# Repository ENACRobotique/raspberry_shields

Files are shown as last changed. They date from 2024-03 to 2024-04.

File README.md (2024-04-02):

# raspberry_shields
Custom shields for raspberrypi

Documentations : 

- [Page wweb raspberrypi](https://www.raspberrypi.com/documentation/computers/raspberry-pi.html)
- [Datasheet BCM2711 ](https://datasheets.raspberrypi.com/bcm2711/bcm2711-peripherals.pdf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..)
 
Les broches des VL53 1 et 2  sont sur des broches pwm

Les uart suivent la norme  Rx, Tx, 3v3, 5v, GND (pdv raspi)

Attention a la configuration PULL UP ou DOWN des gpios ( voir datasheet )

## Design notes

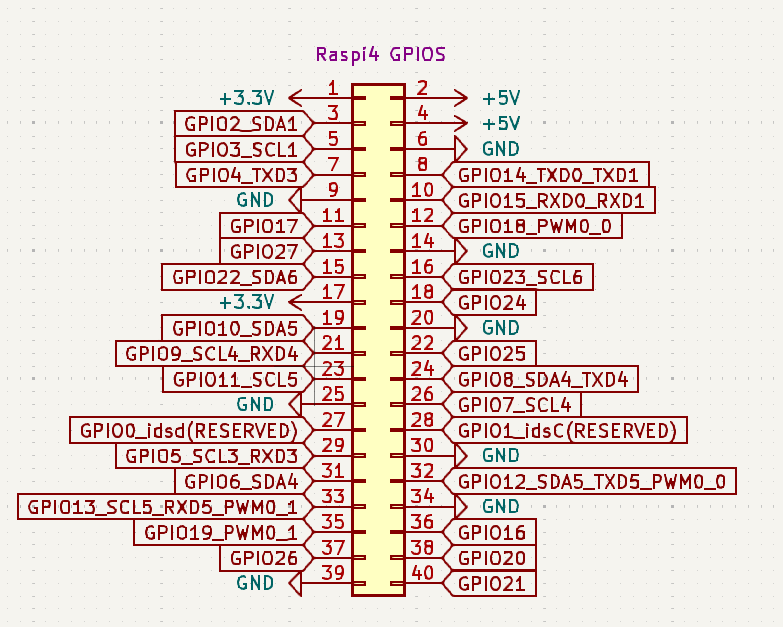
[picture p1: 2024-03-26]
rpi4b/rpi4_gpio.png

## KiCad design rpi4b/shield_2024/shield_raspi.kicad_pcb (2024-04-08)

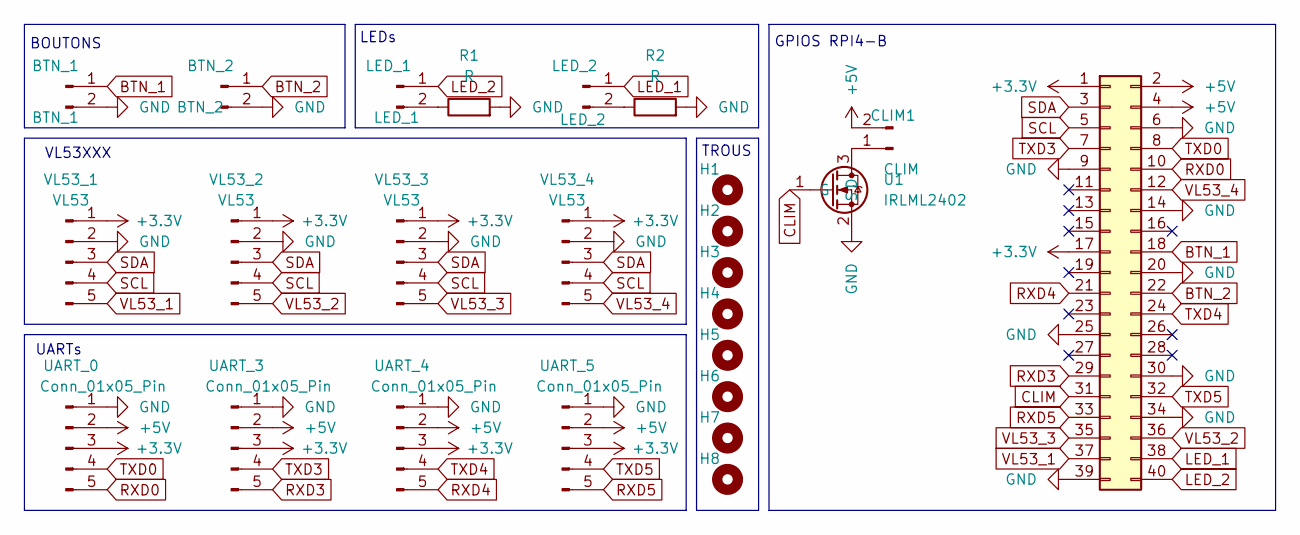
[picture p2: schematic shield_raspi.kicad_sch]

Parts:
BTN_1: BTN_1; PinHeader_1x02_P2.54mm_Vertical
BTN_2: BTN_2; PinHeader_1x02_P2.54mm_Vertical
CLIM1: CLIM; PinHeader_1x02_P2.54mm_Vertical
H1, H2, H3, H4, H5, H6, H7, H8: MountingHole; MountingHole_3.2mm_M3
J4: Conn_02x20_Odd_Even; PinSocket_2x20_P2.54mm_Vertical
LED_1: LED_1; PinHeader_1x02_P2.54mm_Vertical
LED_2: LED_2; PinHeader_1x02_P2.54mm_Vertical
R1, R2: R; R_0603_1608Metric
U1: IRLML2402; SOT-23
UART_0, UART_3, UART_4, UART_5: Conn_01x05_Pin; Molex_CLIK-Mate_502382-0570_1x05-1MP_P1.25mm_Vertical
VL53_1, VL53_2, VL53_3, VL53_4: VL53; PinHeader_1x05_P2.54mm_Vertical

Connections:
+3.3V: J4.1, J4.17, UART_0.3, UART_3.3, UART_4.3, UART_5.3, VL53_1.1, VL53_2.1, VL53_3.1, VL53_4.1
+5V: CLIM1.2, J4.2, J4.4, UART_0.2, UART_3.2, UART_4.2, UART_5.2
BTN_1: BTN_1.1, J4.18
BTN_2: BTN_2.1, J4.22
CLIM: J4.31, U1.1 (G)
GND: BTN_1.2, BTN_2.2, J4.6, J4.9, J4.14, J4.20, J4.25, J4.30, J4.34, J4.39, R1.2, R2.2, U1.2 (S), UART_0.1, UART_3.1, UART_4.1, UART_5.1, VL53_1.2, VL53_2.2, VL53_3.2, VL53_4.2
LED_1: J4.38, LED_2.1
LED_2: J4.40, LED_1.1
unnamed: CLIM1.1, U1.3 (D)
unnamed: LED_1.2, R1.1
unnamed: LED_2.2, R2.1
RXD0: J4.10, UART_0.5
RXD3: J4.29, UART_3.5
RXD4: J4.21, UART_4.5
RXD5: J4.33, UART_5.5
SCL: J4.5, VL53_1.4, VL53_2.4, VL53_3.4, VL53_4.4
SDA: J4.3, VL53_1.3, VL53_2.3, VL53_3.3, VL53_4.3
TXD0: J4.8, UART_0.4
TXD3: J4.7, UART_3.4
TXD4: J4.24, UART_4.4
TXD5: J4.32, UART_5.4
VL53_1: J4.37, VL53_1.5
VL53_2: J4.36, VL53_2.5
VL53_3: J4.35, VL53_3.5
VL53_4: J4.12, VL53_4.5

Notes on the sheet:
VL53XXX
UARTs
LEDs
TROUS
BOUTONS
GPIOS RPI4-B

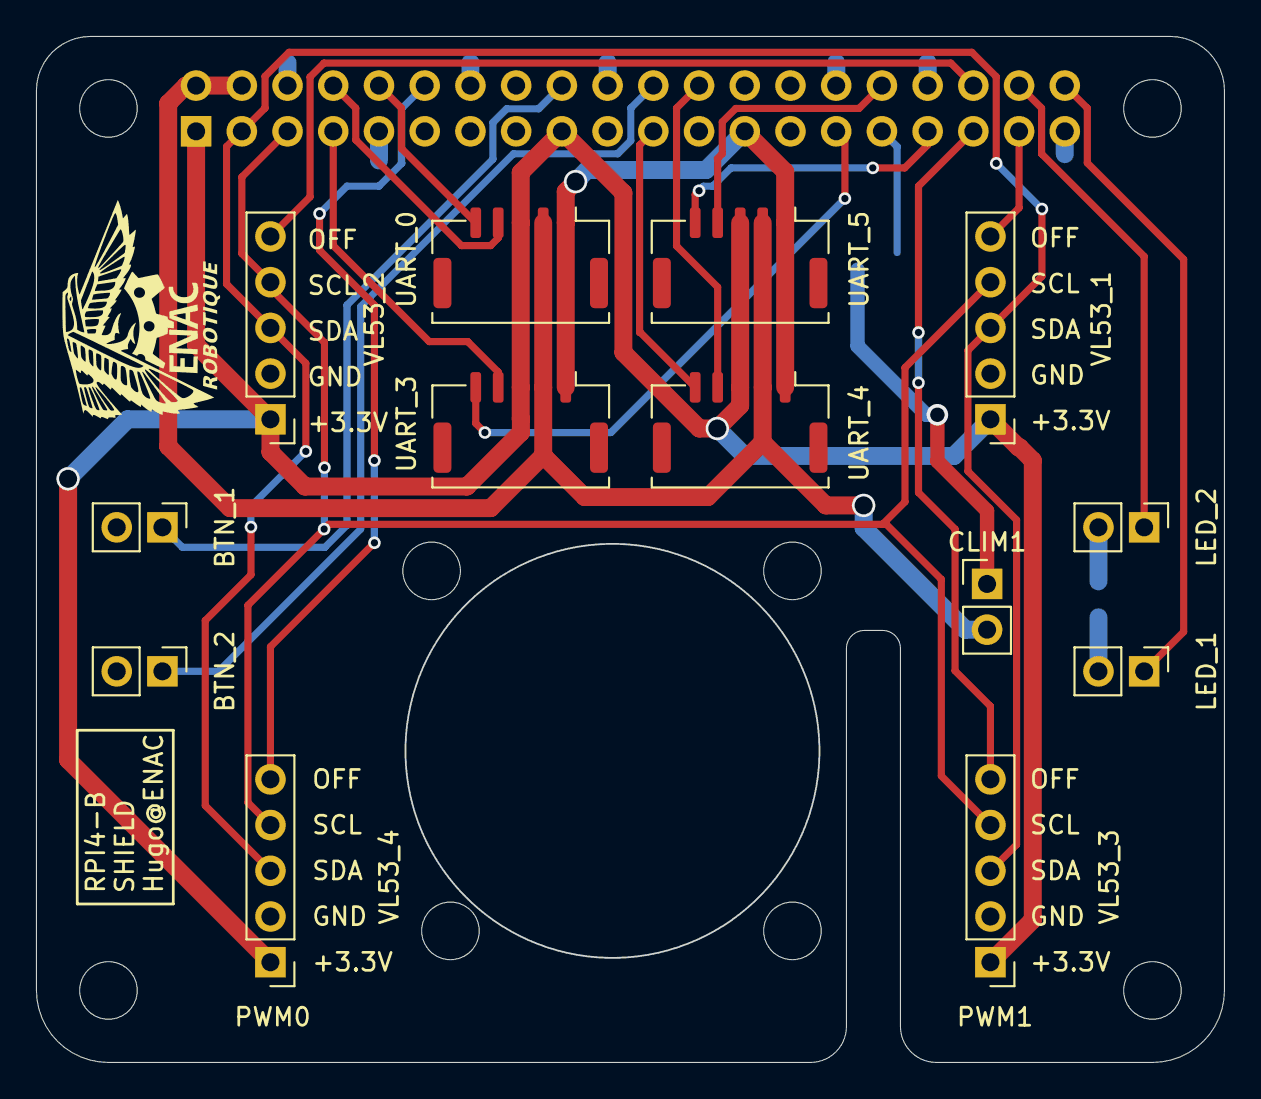
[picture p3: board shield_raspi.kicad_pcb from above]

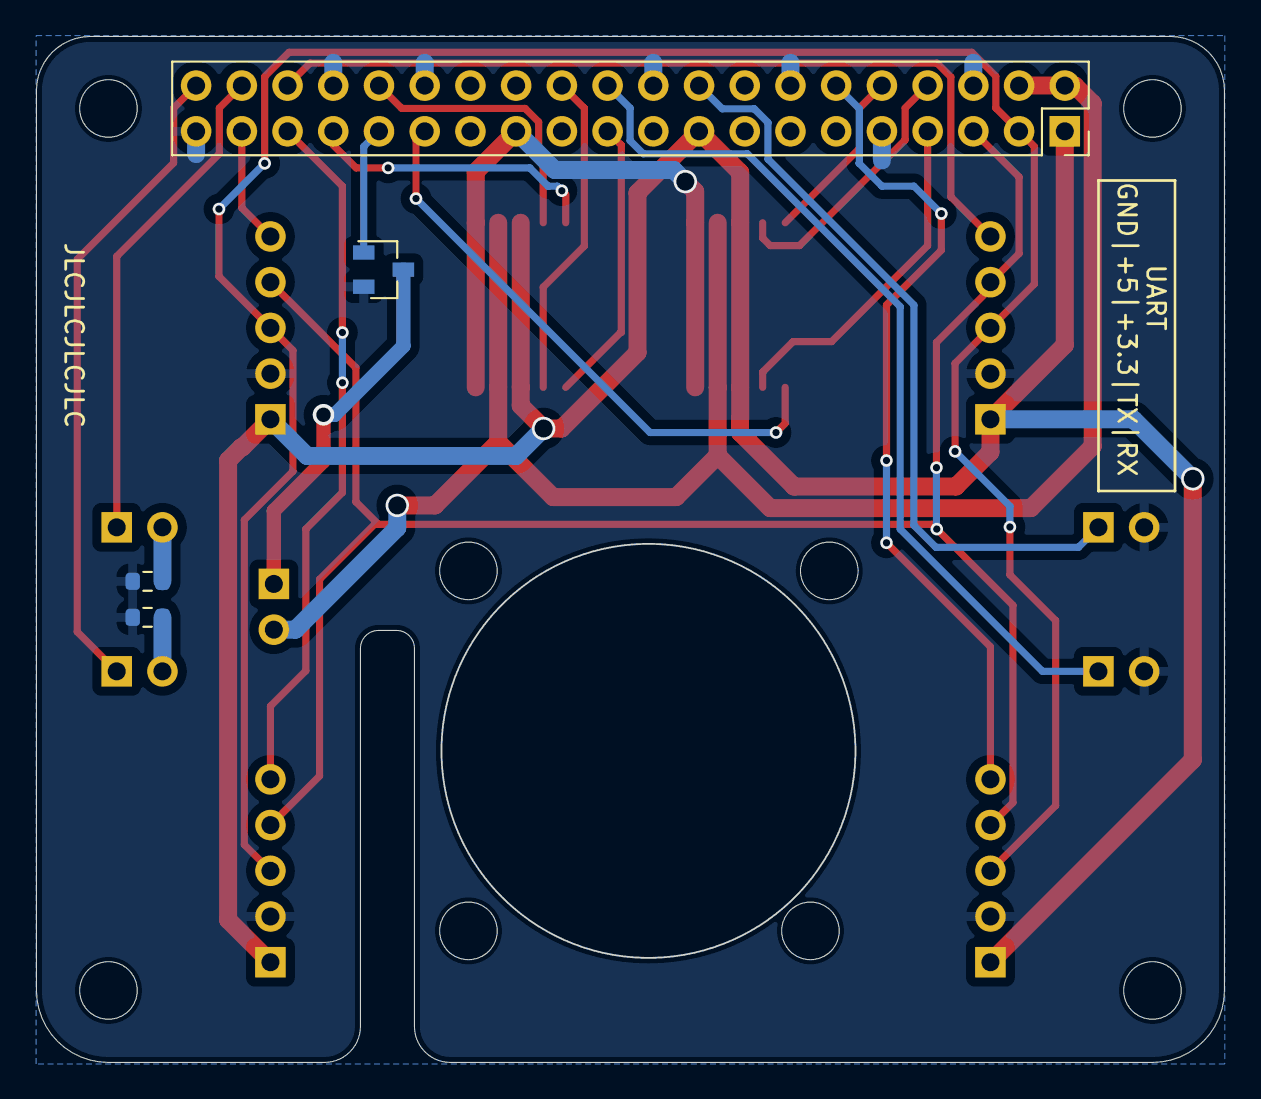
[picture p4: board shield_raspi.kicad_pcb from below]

Board: 2 copper layers, 66.0 x 57.0 mm, 25 parts (4 on the bottom side), 25 nets.

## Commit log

2024-03-26 attribution des pins
    [shield_raspi.kicad_pcb, shield_raspi.kicad_sch]
2024-03-27 placement composant
    [shield_raspi.kicad_pcb, shield_raspi.kicad_sch]
2024-03-27 routage préliminaire
    [shield_raspi.kicad_pcb, shield_raspi.kicad_sch]
2024-03-28 DRC okay, ignore Warnings on H1 & H2 , ready to go
    [shield_raspi.kicad_pcb]
2024-03-29 trou ventilateur + molex
    [shield_raspi.kicad_pcb, shield_raspi.kicad_sch]
2024-04-02 Validation en attente + Add uarts, ventillo
    [shield_raspi.kicad_pcb, shield_raspi.kicad_sch]
2024-04-02 WIP le ventillo
    [shield_raspi.kicad_pcb, shield_raspi.kicad_sch]
2024-04-03 ajout clim , attente de validation
    [shield_raspi.kicad_pcb, shield_raspi.kicad_sch]
2024-04-07 trou caméra
    [shield_raspi.kicad_pcb]
2024-04-08 release V1
    [shield_raspi.kicad_pcb, shield_raspi.kicad_sch]
2024-04-19 modif avec destruction physique
    [shield_raspi.kicad_sch]
